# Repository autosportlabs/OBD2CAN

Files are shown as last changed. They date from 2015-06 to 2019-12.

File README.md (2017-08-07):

OBD2CAN
=======

OBD2CAN allows cars with pre-CAN OBDII enabled ECUs (1996-2007) to emulate a CAN-OBDII interface.

Target
======

OBD2CAN was originally designed as an enhancement to the RaceCapture and RaceCapture/Pro line of hardware, but could theoretically be used with any device that can only communicate with CAN-OBDII enabled ECUs.

Principal of Operation
======================

The operation of OBD2CAN is straightforward:

CAN-OBDII requests are received by OBD2CAN and are forwarded on to the legacy-OBDII interface, using
a STN1110 processor and interface circuitry. 

Legacy-OBDII PID responses are received from the STN1110, and transformed back into the equivalent CAN-OBDII response.

Firmware
========
The firmware is targeted for the STM32F072, and uses ChibiOS as a RTOS. 

Compiling
=========
Compiling requires arm-none-eabi gcc version 4.7.4 20130913

From the firmware directory issue:

> make clean

> make

Flashing
========
* ST bootloader

The firmware image can be flashed using the ST bootloader using the USART1 header after activating BOOT mode. On the OBD2CAN hardware the BOOT jumper pads is adjacent to the USART1 header. The USART header can be connected to a common FTDI 3.3v USB-USART cable (TTL-232R-3V3).

* JTAG SWD

An openocd script is provided to flash the STM32 via SWD, using a ST-LINK/V2

Operation
=========

CAN PID requests are received per OBDII SAE specifications and are translated 1:1 to STN1110 PID requests for the target ECU. 
* 500KBPS
* 11 bit

Protocol is set for automatic detection. 

Diagnostic and command/control CAN messages
===========================================

Control Message
===============
The control message allows some control over the OBD2CAN module's settings

CAN ID: 62344

* Byte 0: Sub command.
 * always 0x01

* Byte 1: Debug level on UART header
 * 0: no logging
 * 1: info level logging
 * 2: trace level logging

* Byte 2: Reset STN1110
 * 0: do not reset
 * 1: perform a hard reset

* Byte 3: Set OBDII protocol
Affects AT SP command, see ELM327 manual. If different than the current setting, triggers a reset of the STN1110
 * 0: auto detect (power up default)
 * 1: J1850 PWM
 * 2: J1850 VPW
 * 3: ISO 9141-2
 * 4: ISO 14230-4

Diagnostic
==========
The OBD2CAN will broadcast a diagnostic message at 1Hz with the following information:

CAN ID: 62345

* Byte 0: Detected protocol
 * 0: auto detect (still detecting)
 * 1: J1850 PWM
 * 2: J1850 VPW
 * 3: ISO 9141-2
 * 4: ISO 14230-4

* Byte 1: Last error code
 * 0: STN1110_ERROR_NONE,
 * 1: STN1110_ERROR_STOPPED,
 * 2: STN1110_ERROR_NO_DATA,
 * 3: STN1110_ERROR_BUS_INIT

* Byte 2-3: STN1110 request/reply latency, in ms. 
 * Little Endian

* Byte 4: reserved

* Byte 5: firmware major version

* Byte 6: firmware minor version

* Byte 7: firmware patch version

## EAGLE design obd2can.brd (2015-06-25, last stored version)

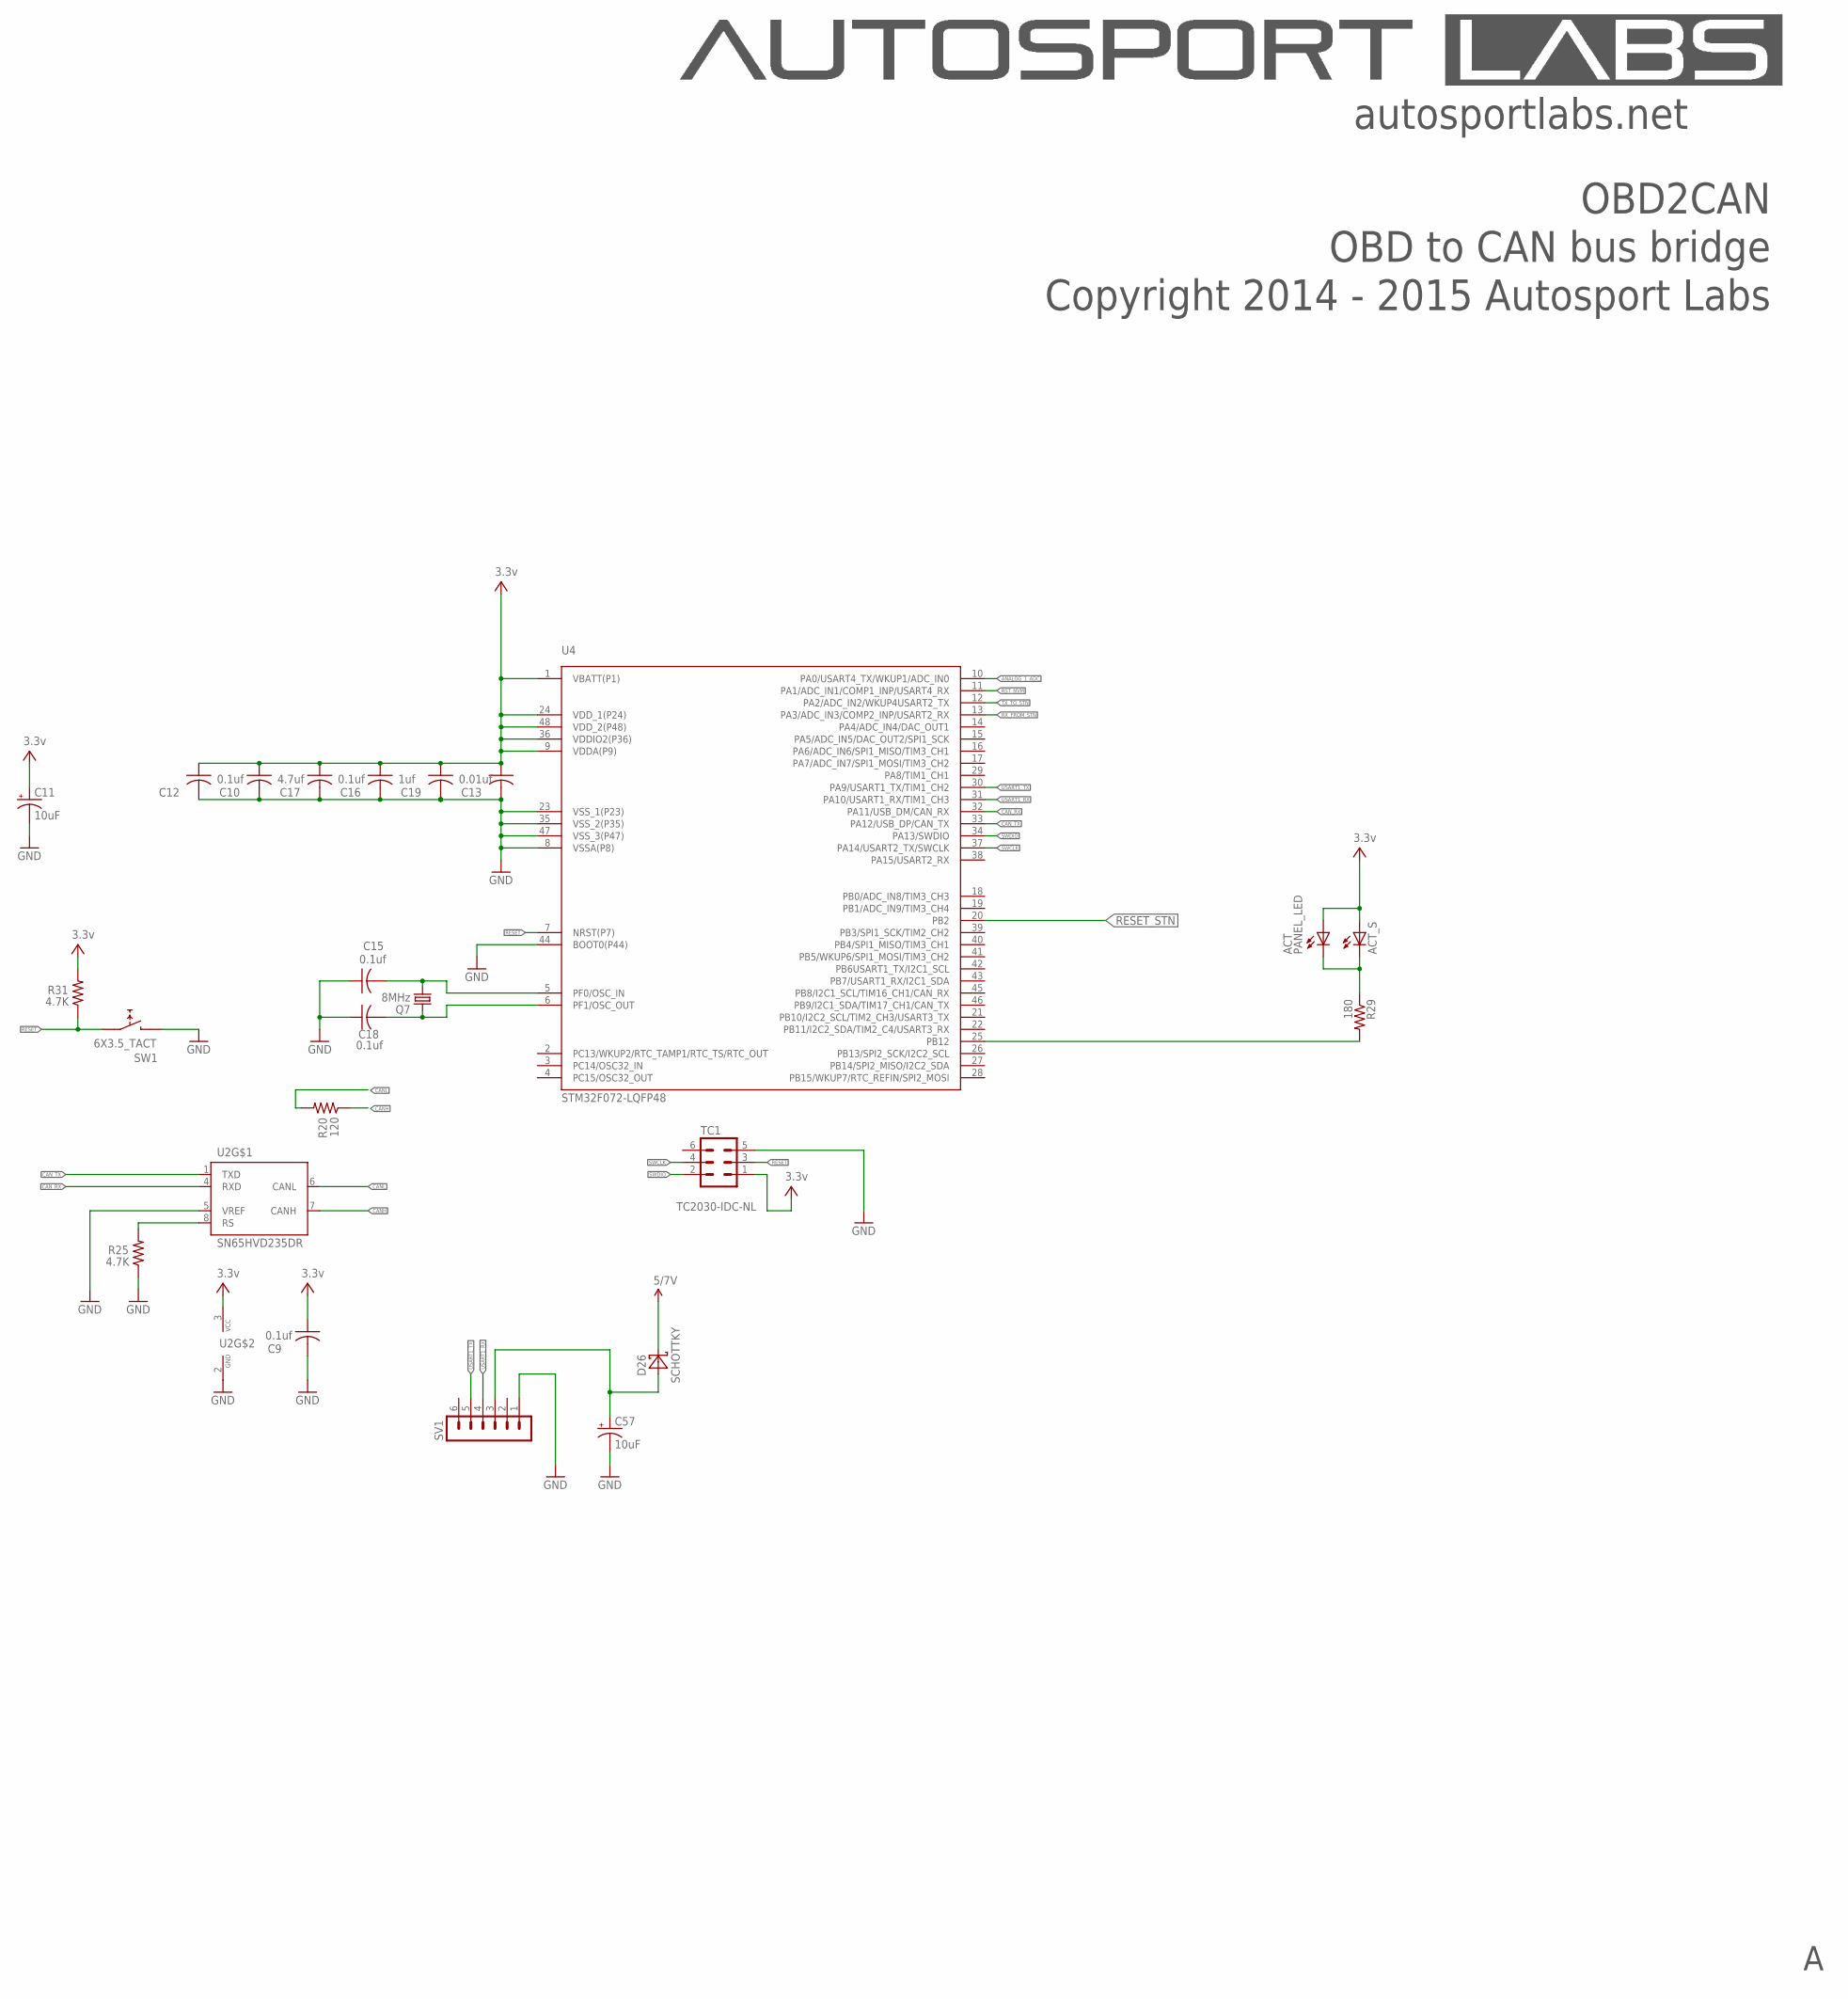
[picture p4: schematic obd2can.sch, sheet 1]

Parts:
ACT: PANEL_LED; RIGHTANGLE_CML_5323F5
ACT_S: LEDCHIPLED_0603; CHIPLED_0603
C9, C10, C15, C16, C18: 0.1uf; C0603K
C11, C57: 10uF; SMC_A
C12, C17: 4.7uf; C0603K
C13: 0.01uf; C0603K
C19: 1uf; C0603K
D26: SCHOTTKY; SMA
Q7: 8MHz; CRYSTAL-SMD-5X3
R20: 120; R0603
R25, R31: 4.7K; R0603
R29: 180; 0402-RES
SV1: MA06-1
SW1: 6X3.5_TACT; TACT_6X3.5
TC1: TC2030-IDC-NL
U2: SN65HVD235DR; SO08
U4: STM32F072-LQFP48; LQFP48

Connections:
ANALOG_1_ADC: U4.10 (PA0/USART4_TX/WKUP1/ADC_IN0)
CANH: R20.1, U2.7 (CANH); also elsewhere on the board
CANL: R20.2, U2.6 (CANL); also elsewhere on the board
CAN_RX: U2.4 (RXD), U4.32 (PA11/USB_DM/CAN_RX)
CAN_TX: U2.1 (TXD), U4.33 (PA12/USB_DP/CAN_TX)
GND: C9.2, C10.2, C11.-, C12.2, C13.2, C15.1, C16.2, C17.2, C18.1, C19.2, C57.-, R25.1, SV1.1, SW1.P$2 (2), TC1.5, U2.2 (GND), U2.5 (VREF), U4.8 (VSSA(P8)), U4.23 (VSS_1(P23)), U4.35 (VSS_2(P35)), U4.44 (BOOT0(P44)), U4.47 (VSS_3(P47)); also elsewhere on the board
GND1: ACT.C, ACT_S.C, R29.1
unnamed: R29.2, U4.25 (PB12)
unnamed: R25.2, U2.8 (RS)
unnamed: C18.2, Q7.3 (2), U4.6 (PF1/OSC_OUT)
unnamed: C15.2, Q7.1, U4.5 (PF0/OSC_IN)
RESET: R31.1, SW1.P$1 (1), TC1.3, U4.7 (NRST(P7))
RESET_STN: U4.20 (PB2); also elsewhere on the board
RST_NVM: U4.11 (PA1/ADC_IN1/COMP1_INP/USART4_RX); also elsewhere on the board
RX_FROM_STN: U4.13 (PA3/ADC_IN3/COMP2_INP/USART2_RX); also elsewhere on the board
SWCLK: TC1.4, U4.37 (PA14/USART2_TX/SWCLK)
SWDIO: TC1.2, U4.34 (PA13/SWDIO)
TX_TO_STN: U4.12 (PA2/ADC_IN2/WKUP4USART2_TX); also elsewhere on the board
USART1_RX: SV1.4, U4.31 (PA10/USART1_RX/TIM1_CH3)
USART1_TX: SV1.5, U4.30 (PA9/USART1_TX/TIM1_CH2)
V+: ACT.A, ACT_S.A, C9.1, C10.1, C11.+, C12.1, C13.1, C16.1, C17.1, C19.1, R31.2, TC1.1, U2.3 (VCC), U4.1 (VBATT(P1)), U4.9 (VDDA(P9)), U4.24 (VDD_1(P24)), U4.36 (VDDIO2(P36)), U4.48 (VDD_2(P48)); also elsewhere on the board
VBUS: C57.+, D26.A, SV1.3
VCC: D26.C; also elsewhere on the board

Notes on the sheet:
Copyright 2014 - 2015 Autosport Labs
OBD2CAN
autosportlabs.net
OBD to CAN bus bridge

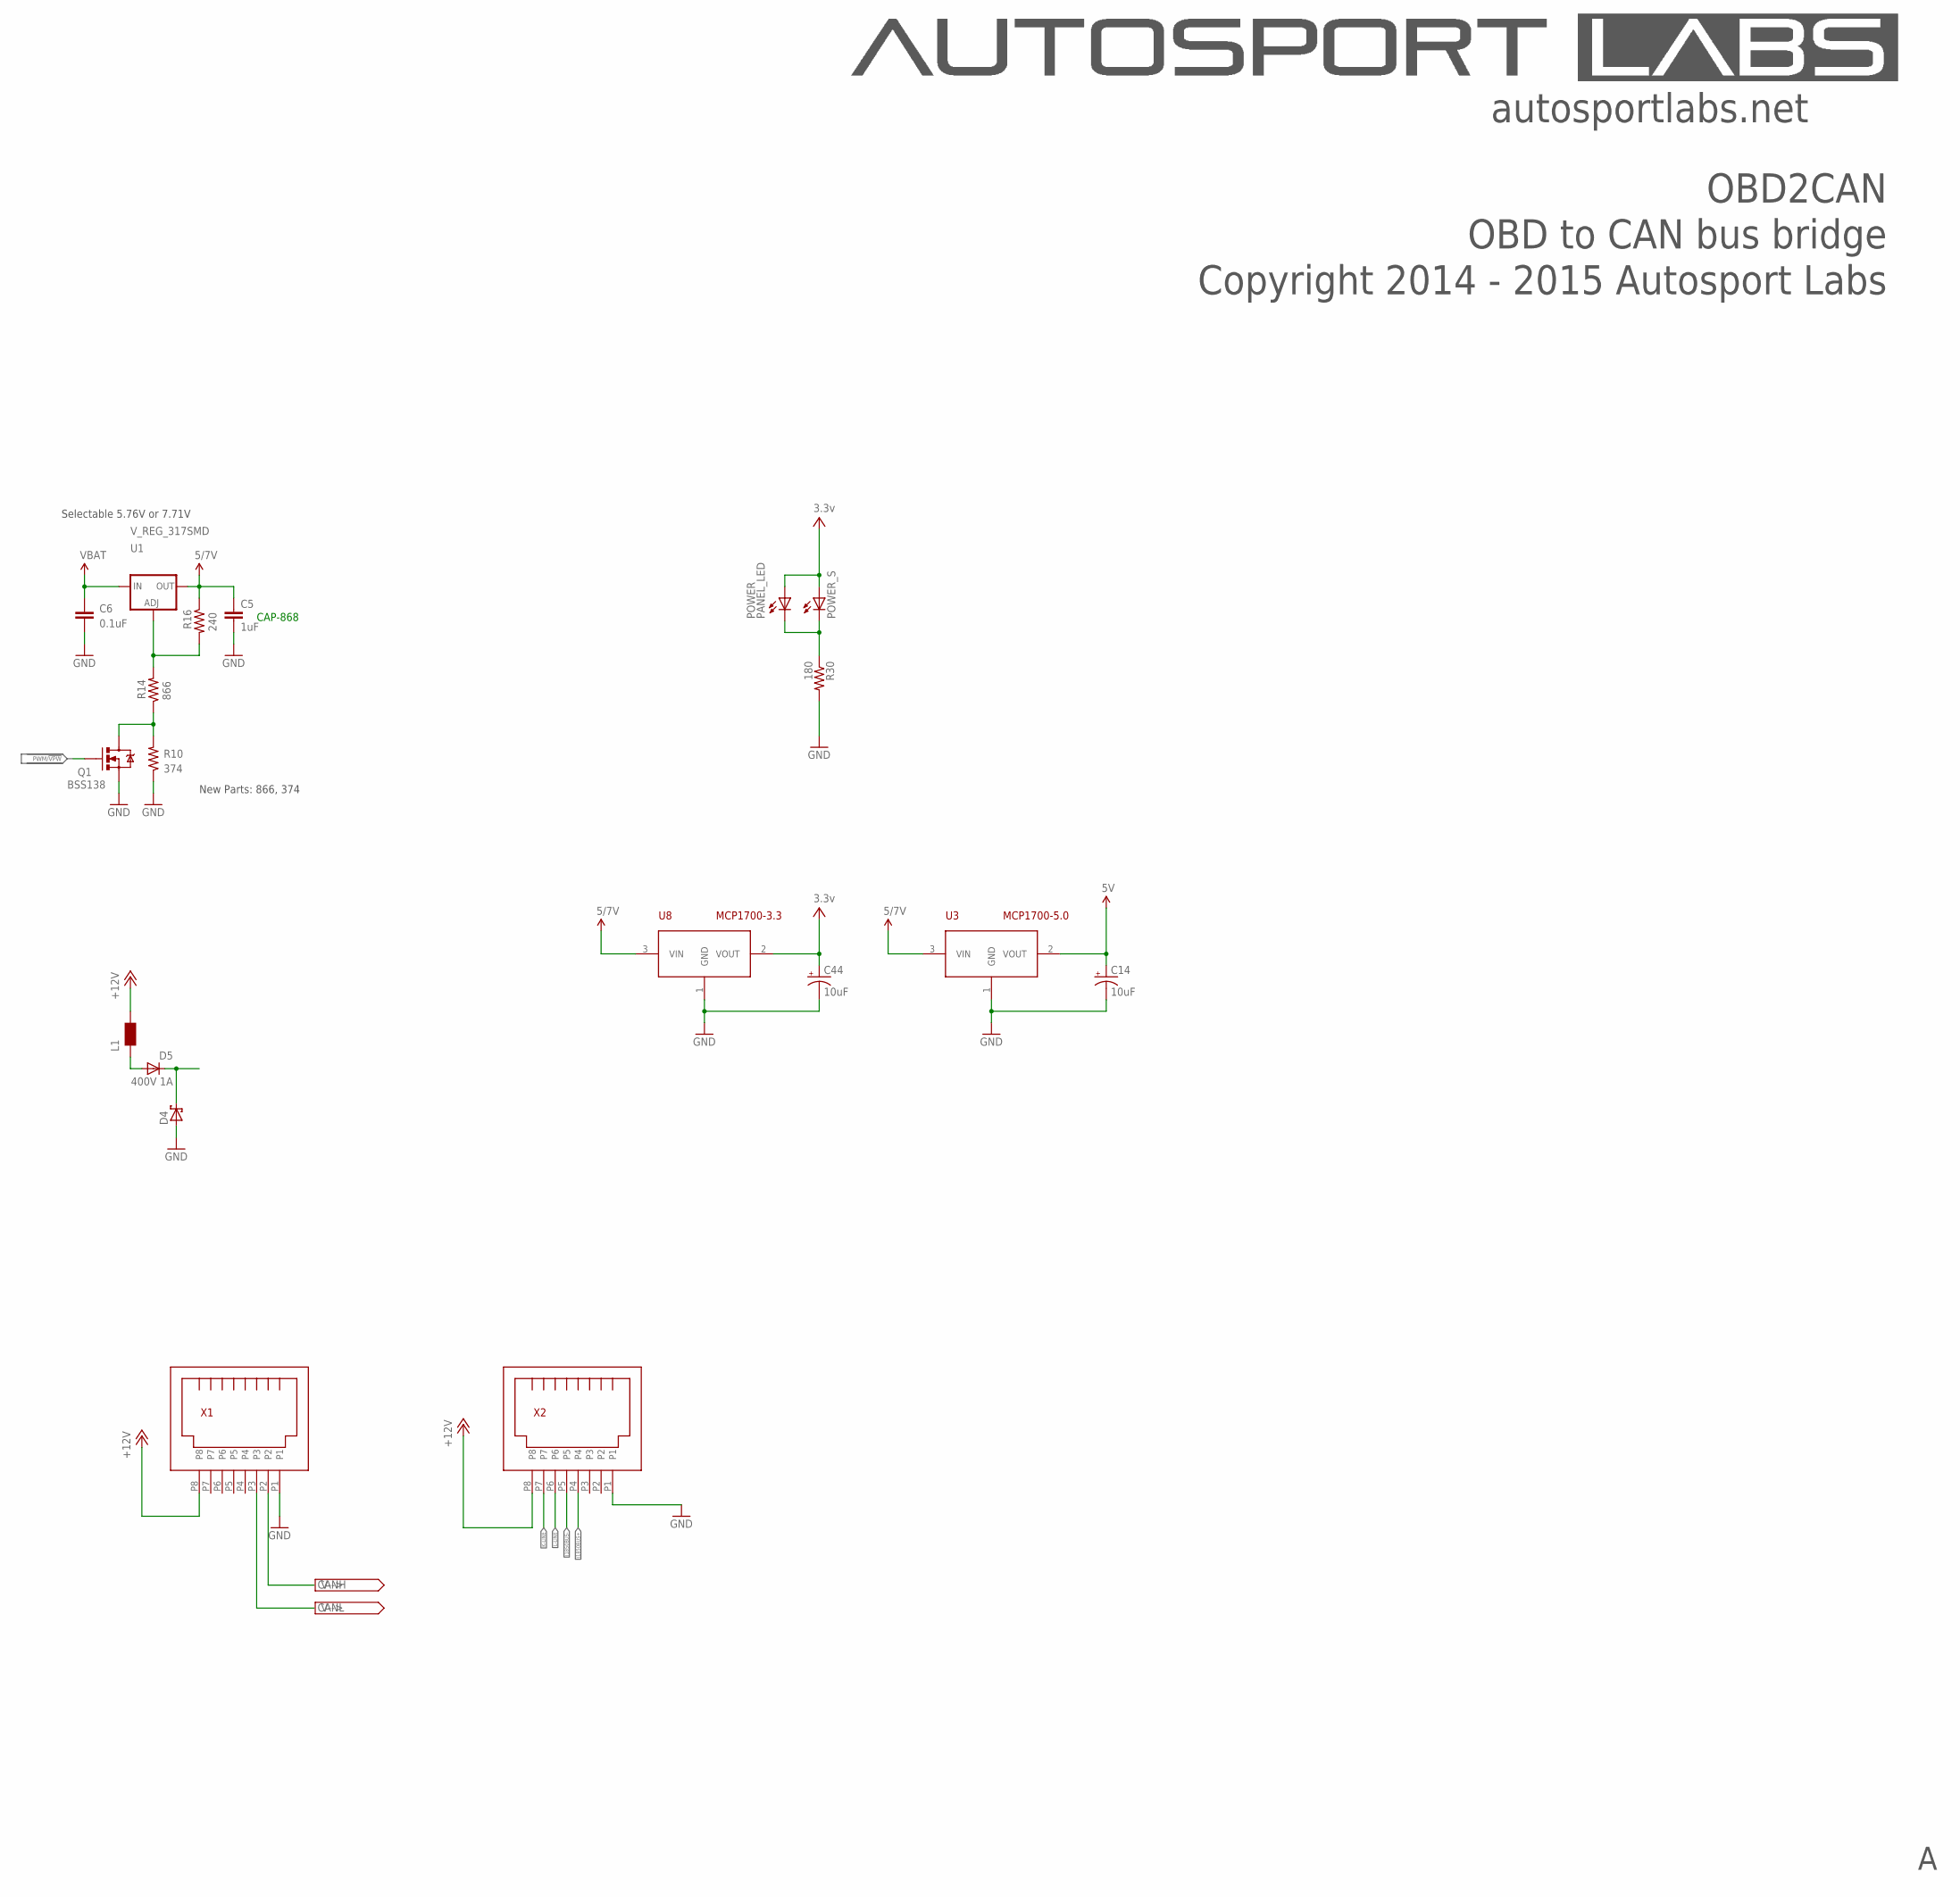
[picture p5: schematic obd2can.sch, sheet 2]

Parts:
C5: 1uF; 0402-CAP
C6: 0.1uF; 0402-CAP
C14, C44: 10uF; SMC_A
D4: SCHOTTKY-DIODESMC; SMC
D5: 400V 1A; SMA
L1: WE-CBF_1812; 1812
POWER: PANEL_LED; RIGHTANGLE_CML_5323F5
POWER_S: LEDCHIPLED_0603; CHIPLED_0603
Q1: BSS138; SOT23-3
R10: 374; 0402-RES
R14: 866; 0402-RES
R16: 240; 0402-RES
R30: 180; 0402-RES
U1: V_REG_317SMD; SOT223
U3: MCP1700-5.0; SOT-23
U8: MCP1700-3.3; SOT-23
X1, X2: RJ45_RIGHT_ANGLEMOLEX_95001-2881; RJ45_RIGHT_ANGLE_MOLEX_95001-2881

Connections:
5V: C14.+, U3.2 (VOUT); also elsewhere on the board
+12V: L1.2, X1.P8, X2.P8; also elsewhere on the board
CANH: X1.P2; also elsewhere on the board
CANL: X1.P3; also elsewhere on the board
GND: C5.2, C6.2, C14.-, C44.-, D4.A, Q1.2 (S), R10.1, R30.2, U3.1 (GND), U8.1 (GND), X1.P1, X2.P1; also elsewhere on the board
GND2: POWER.C, POWER_S.C, R30.1
J1850BUS+: X2.P4; also elsewhere on the board
J1850BUS-: X2.P5; also elsewhere on the board
K-LINE: X2.P7; also elsewhere on the board
L-LINE: X2.P6; also elsewhere on the board
unnamed: R14.2, R16.2, U1.1 (ADJ)
unnamed: Q1.3 (D), R10.2, R14.1
unnamed: D5.A, L1.1
PWM/!VPW: Q1.1 (G); also elsewhere on the board
SAFE12V: C6.1, D4.C, D5.C, U1.3 (IN); also elsewhere on the board
V+: C44.+, POWER.A, POWER_S.A, U8.2 (VOUT); also elsewhere on the board
VCC: C5.1, R16.1, U1.2 (OUT), U3.3 (VIN), U8.3 (VIN); also elsewhere on the board

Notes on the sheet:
Copyright 2014 - 2015 Autosport Labs
OBD2CAN
autosportlabs.net
OBD to CAN bus bridge
Selectable 5.76V or 7.71V
New Parts: 866, 374
CAP-868

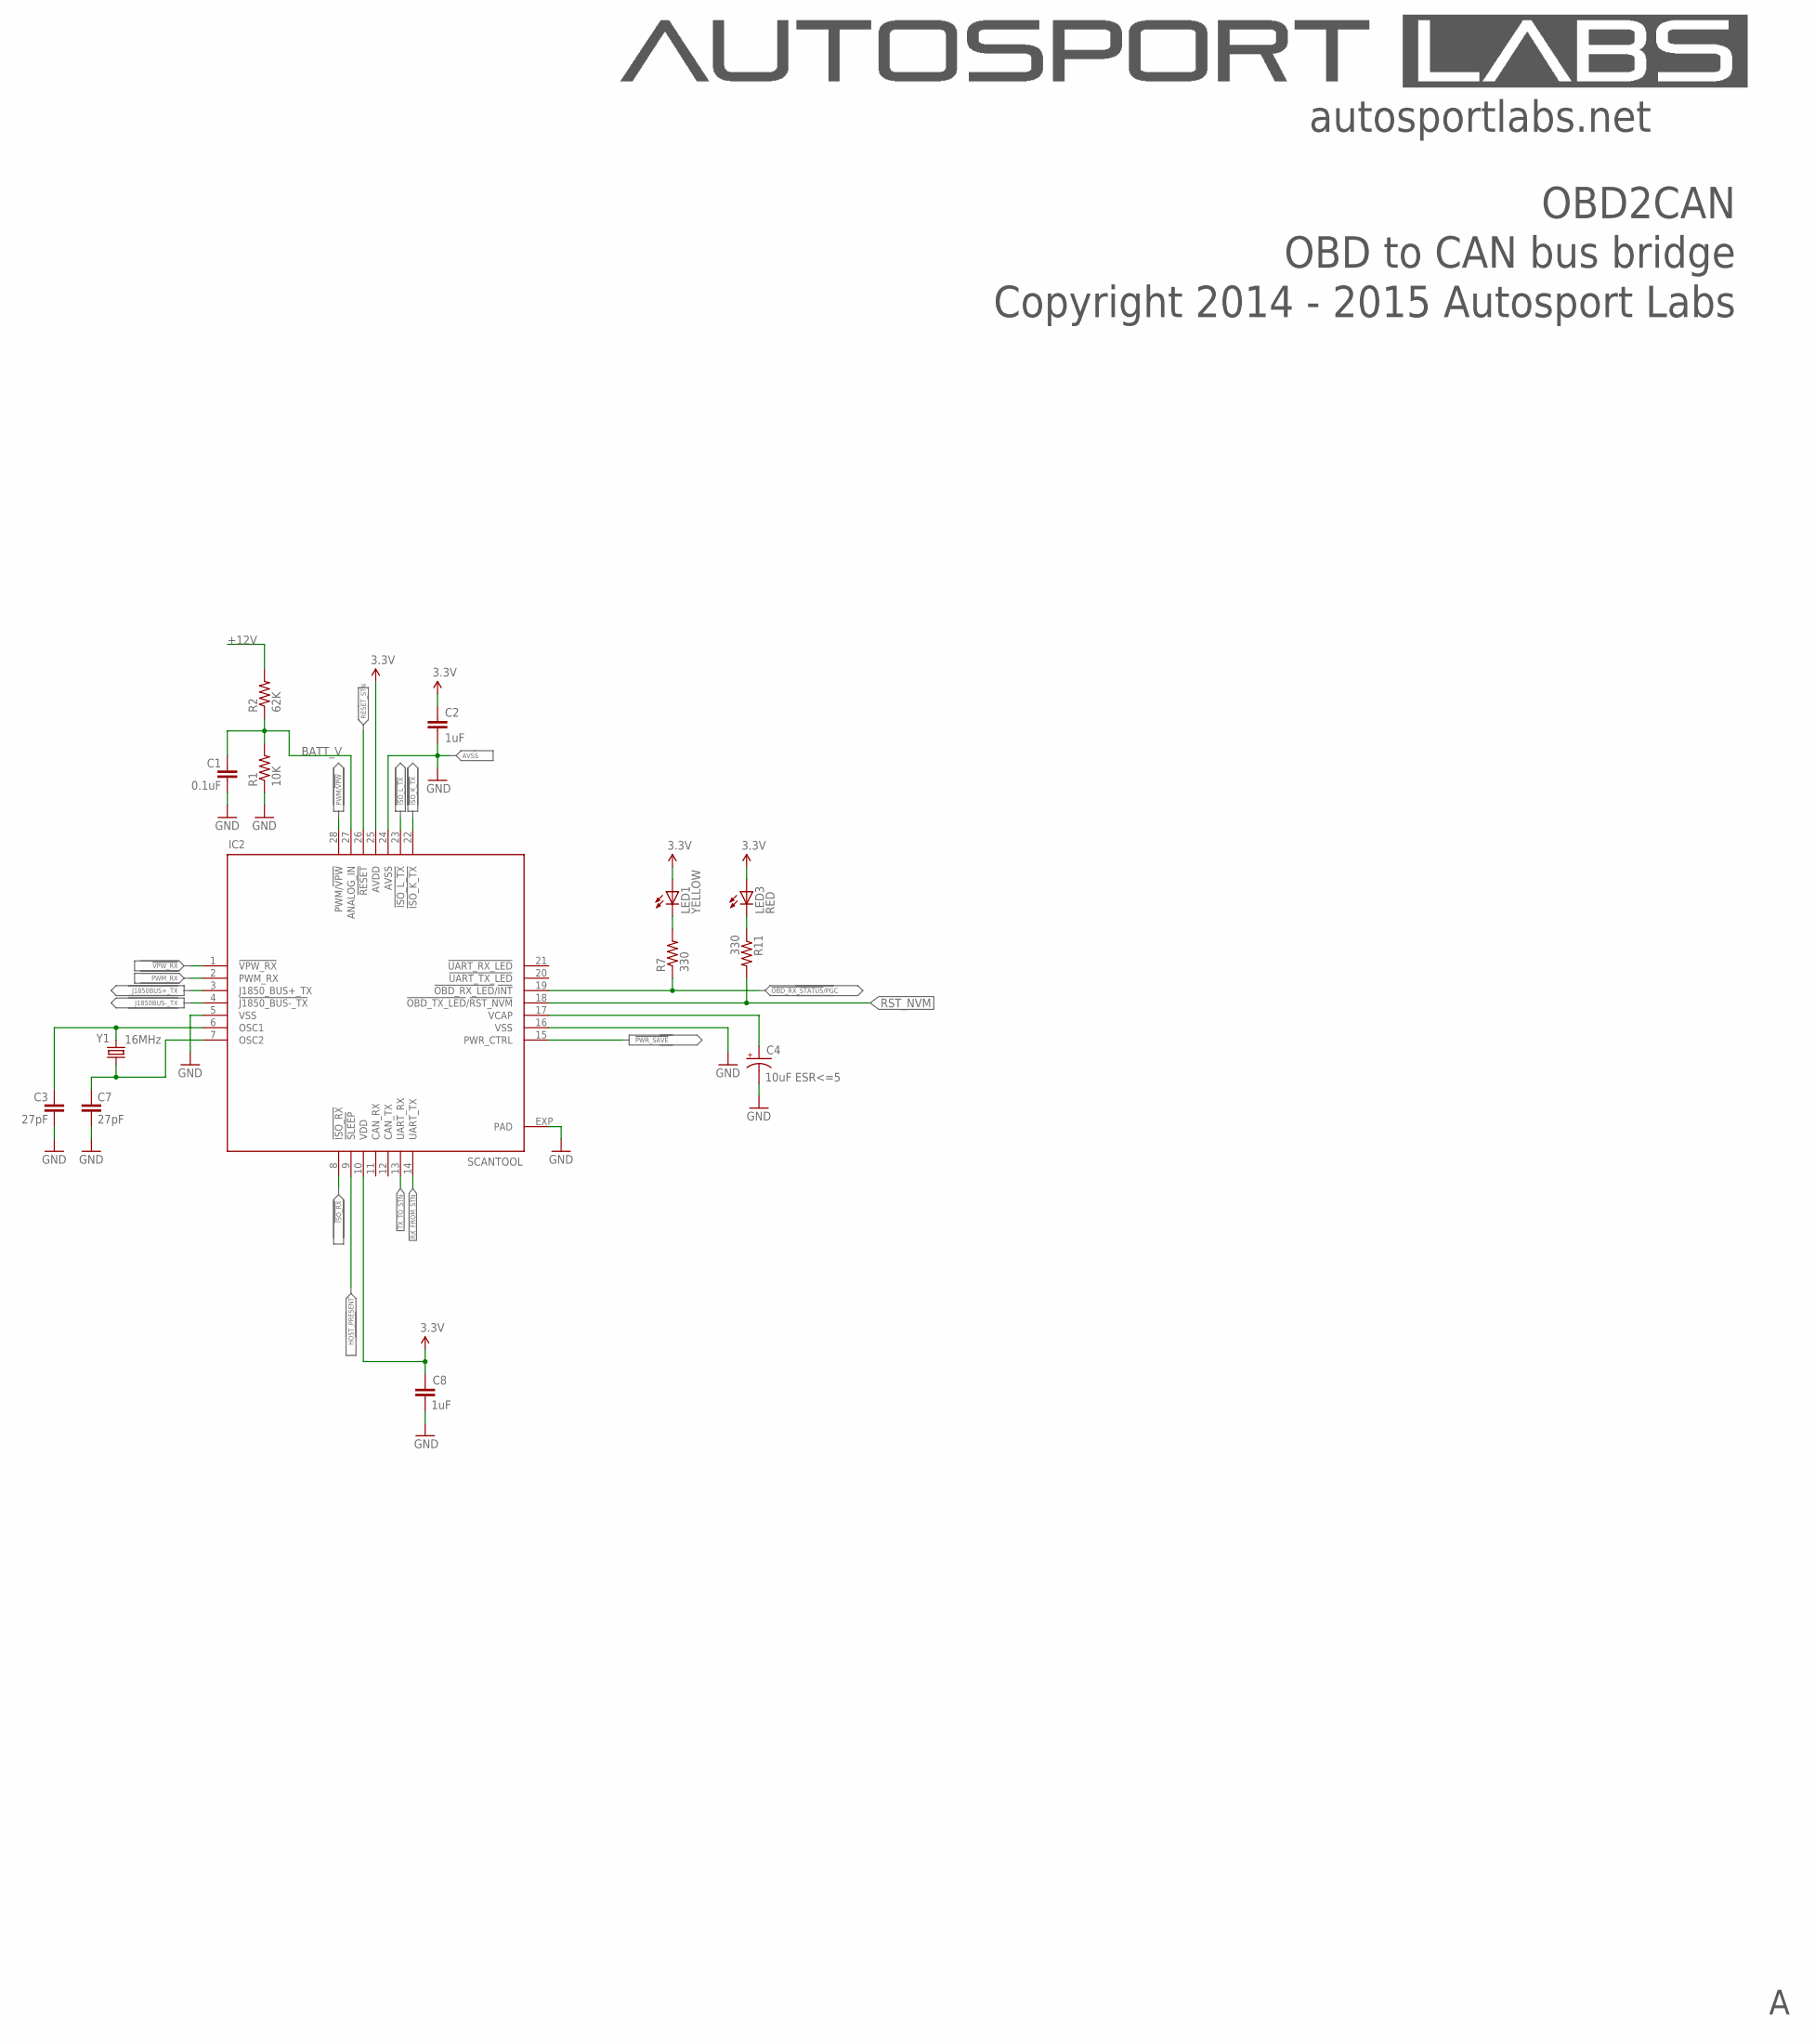
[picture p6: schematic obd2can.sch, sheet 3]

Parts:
C1: 0.1uF; 0402-CAP
C2, C8: 1uF; 0402-CAP
C3, C7: 27pF; 0402-CAP
C4: 10uF ESR<=5; EIA3216
IC2: SCANTOOL; _STN_SCANTOOL_QFN-28-S
LED1: YELLOW; LED-0603
LED3: RED; LED-0603
R1: 10K; 0402-RES
R2: 62K; 0402-RES
R7, R11: 330; 0402-RES
Y1: 16MHz; CRYSTAL-SMD-5X3

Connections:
!ISO_K_TX: IC2.22 (!ISO_K_TX); also elsewhere on the board
!ISO_L_TX: IC2.23 (!ISO_L_TX); also elsewhere on the board
!ISO_RX: IC2.8 (!ISO_RX); also elsewhere on the board
!OBD_RX_STATUS!/PGC: IC2.19 (!OBD_RX_LED!/!INT), R7.1
!PWR_SAVE: IC2.15 (PWR_CTRL)
!VPW_RX: IC2.1 (!VPW_RX); also elsewhere on the board
+12V: R2.2; also elsewhere on the board
BATT_V: C1.1, IC2.27 (ANALOG_IN), R1.2, R2.1
GND: C1.2, C2.2, C3.2, C4.C (-), C7.2, C8.2, IC2.5 (VSS), IC2.16 (VSS), IC2.24 (AVSS), IC2.EXP (PAD), R1.1; also elsewhere on the board
HOST_PRESENT: IC2.9 (!SLEEP)
J1850BUS+_TX: IC2.3 (J1850_BUS+_TX); also elsewhere on the board
J1850BUS-_TX: IC2.4 (!J1850_BUS-_TX); also elsewhere on the board
unnamed: C4.A (+), IC2.17 (VCAP)
unnamed: LED1.C, R7.2
unnamed: LED3.C, R11.1
OSC1: C3.1, IC2.6 (OSC1), Y1.3 (2)
OSC2: C7.1, IC2.7 (OSC2), Y1.1
PWM/!VPW: IC2.28 (PWM/!VPW); also elsewhere on the board
PWM_RX: IC2.2 (PWM_RX); also elsewhere on the board
RESET_STN: IC2.26 (!RESET); also elsewhere on the board
RST_NVM: IC2.18 (!OBD_TX_LED!/!RST_NVM), R11.2; also elsewhere on the board
RX_FROM_STN: IC2.14 (UART_TX); also elsewhere on the board
TX_TO_STN: IC2.13 (UART_RX); also elsewhere on the board
V+: C2.1, C8.1, IC2.10 (VDD), IC2.25 (AVDD), LED1.A, LED3.A; also elsewhere on the board

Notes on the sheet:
AVSS
Copyright 2014 - 2015 Autosport Labs
OBD2CAN
autosportlabs.net
OBD to CAN bus bridge

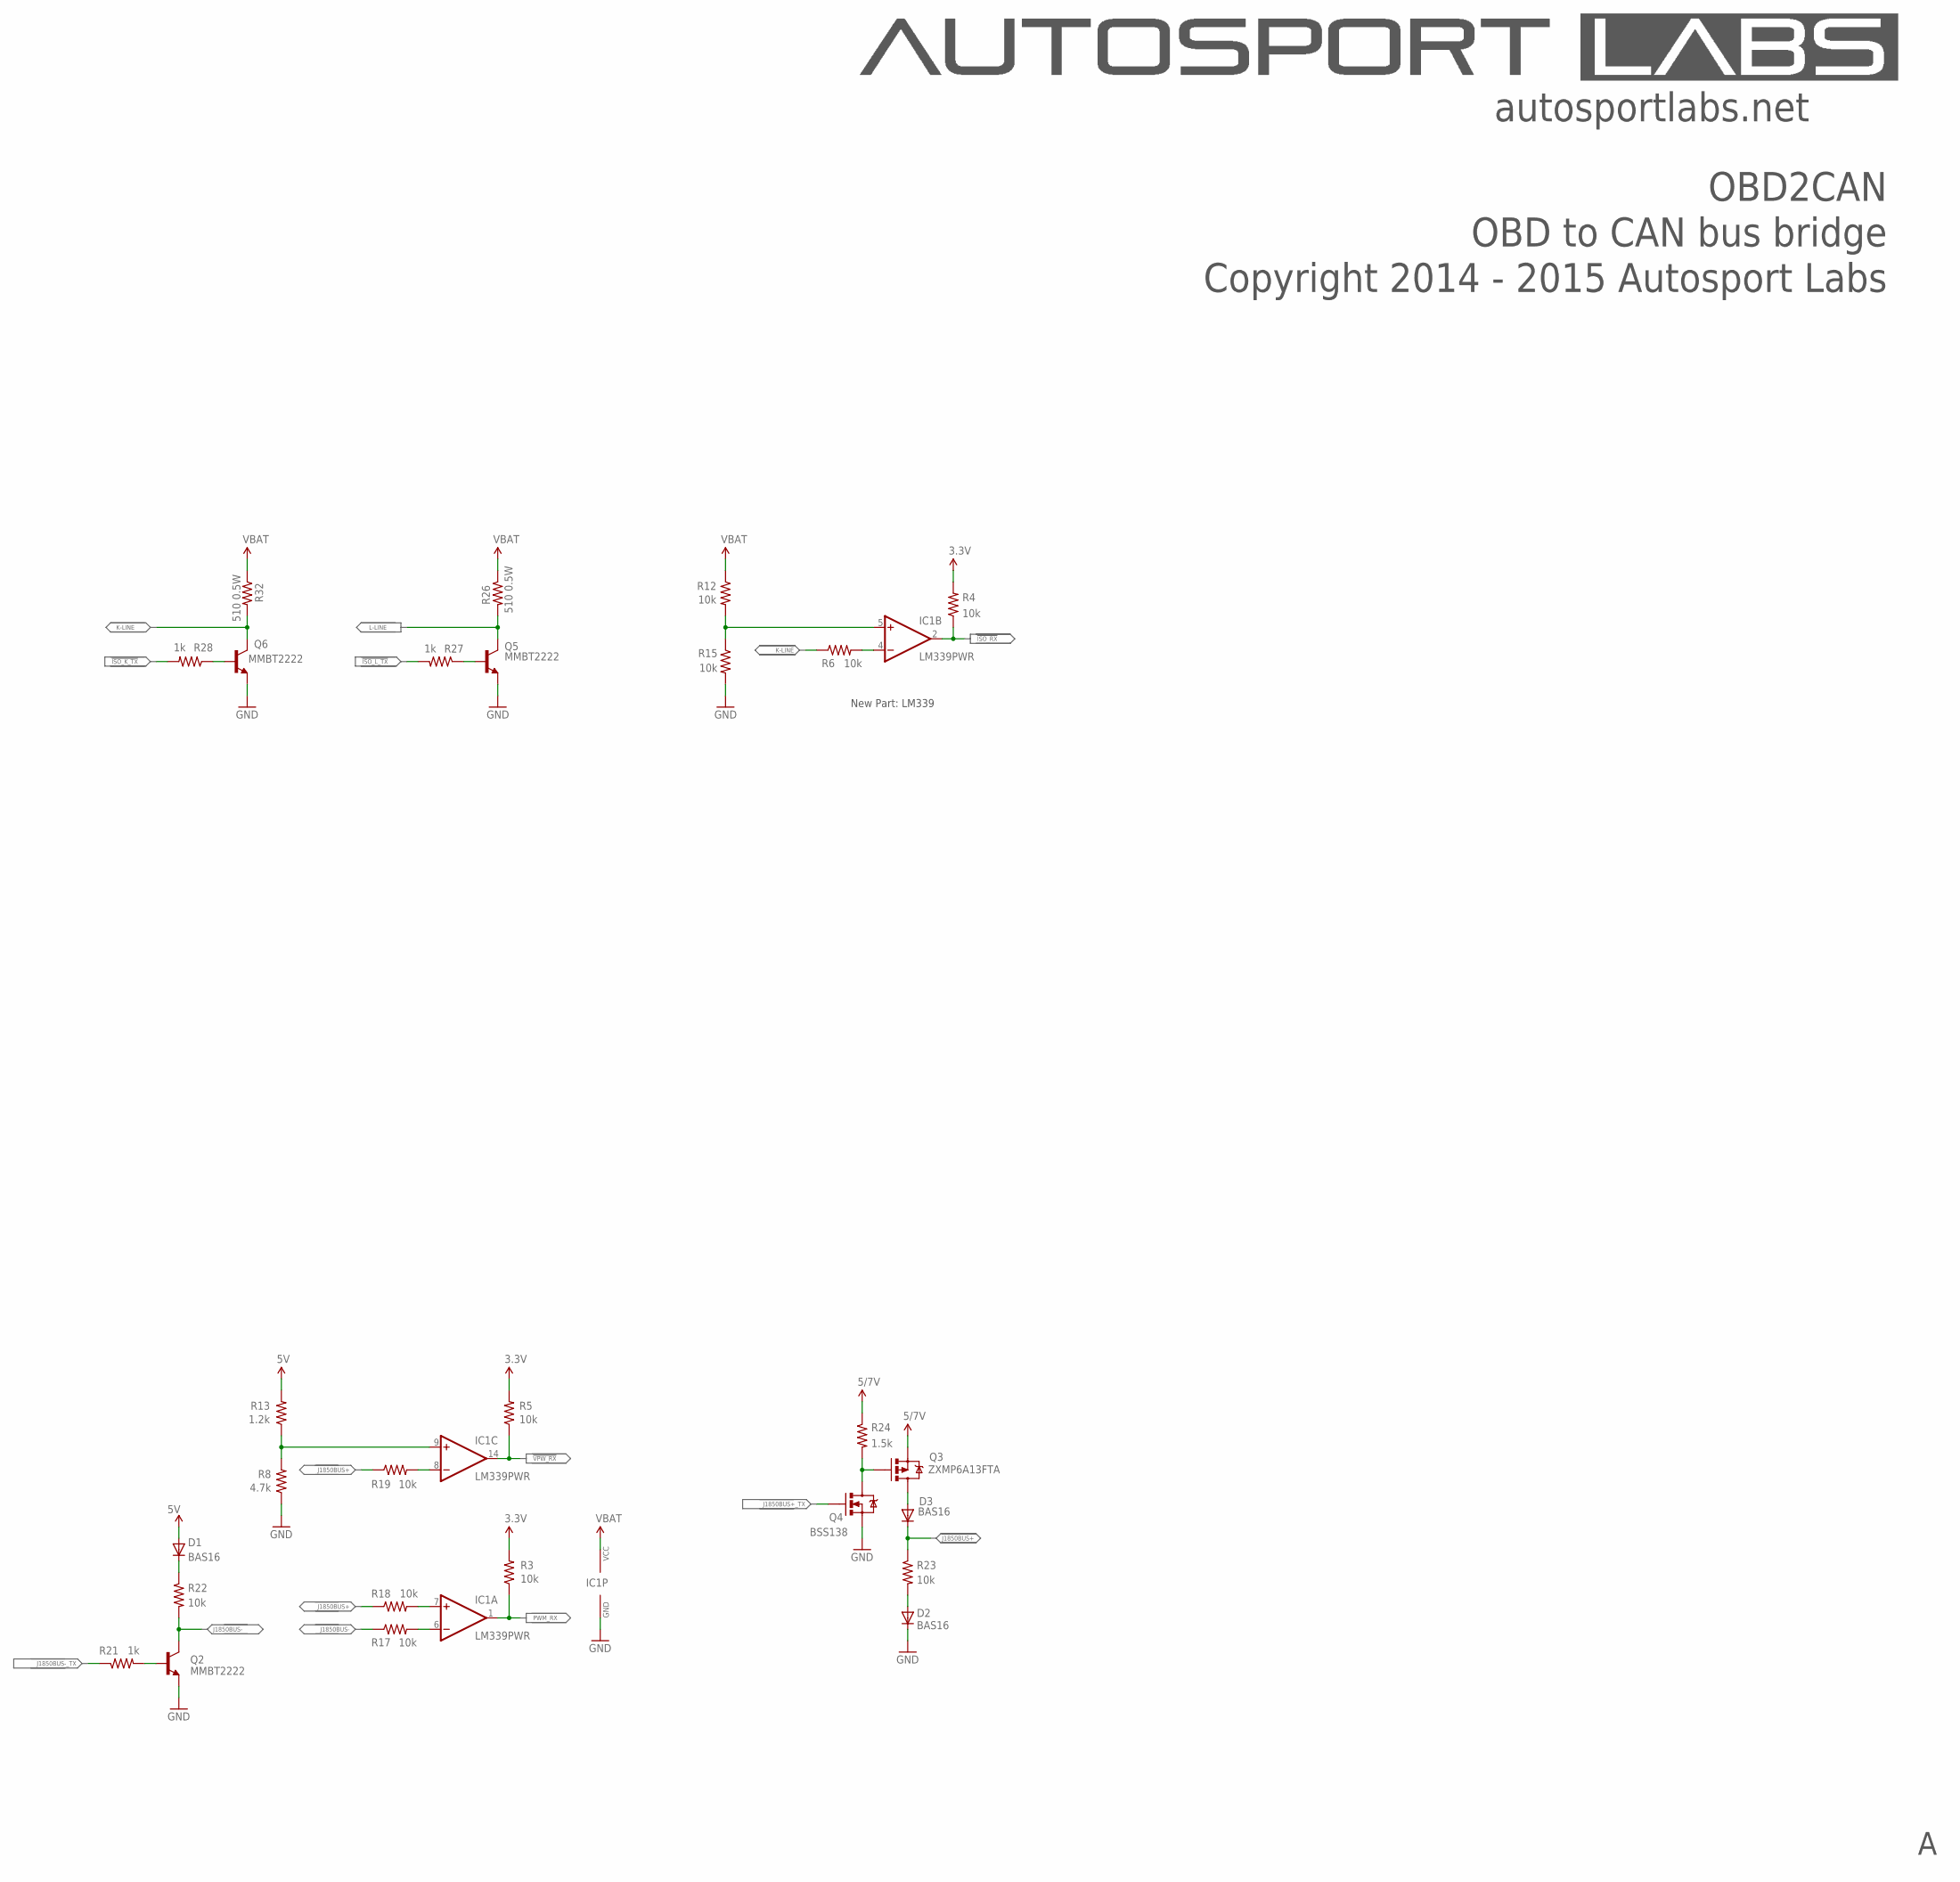
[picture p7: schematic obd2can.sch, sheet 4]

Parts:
D1, D2, D3: BAS16; SOD-323
IC1: LM339PWR; TSSOP-14
Q2, Q5, Q6: MMBT2222; SOT23-3
Q3: ZXMP6A13FTA; SOT23
Q4: BSS138; SOT23-3
R3, R4, R5, R6, R12, R15, R17, R18, R19, R22, R23: 10k; 0402-RES
R8: 4.7k; 0402-RES
R13: 1.2k; 0402-RES
R21, R27, R28: 1k; 0402-RES
R24: 1.5k; 0402-RES
R26, R32: 510 0.5W; 2010

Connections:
5V: D1.2 (A), R13.2; also elsewhere on the board
!ISO_K_TX: R28.2; also elsewhere on the board
!ISO_L_TX: R27.2; also elsewhere on the board
!ISO_RX: IC1.2 (OUT), R4.1; also elsewhere on the board
!VPW_RX: IC1.14 (OUT), R5.1; also elsewhere on the board
GND: D2.1 (C), IC1.12 (GND), Q2.2 (E), Q4.2 (S), Q5.2 (E), Q6.2 (E), R8.1, R15.2; also elsewhere on the board
J1850BUS+: D3.1 (C), R18.1, R19.1, R23.1; also elsewhere on the board
J1850BUS+_TX: Q4.1 (G); also elsewhere on the board
J1850BUS-: Q2.3 (C), R17.1, R22.2; also elsewhere on the board
J1850BUS-_TX: R21.1; also elsewhere on the board
K-LINE: Q6.3 (C), R6.1, R32.2; also elsewhere on the board
L-LINE: Q5.3 (C), R26.2; also elsewhere on the board
unnamed: IC1.7 (+IN), R18.2
unnamed: IC1.6 (-IN), R17.2
unnamed: Q6.1 (B), R28.1
unnamed: Q5.1 (B), R27.1
unnamed: IC1.5 (+IN), R12.2, R15.1
unnamed: IC1.8 (-IN), R19.2
unnamed: D3.2 (A), Q3.3 (D)
unnamed: IC1.9 (+IN), R8.2, R13.1
unnamed: IC1.4 (-IN), R6.2
unnamed: D1.1 (C), R22.1
unnamed: Q3.1 (G), Q4.3 (D), R24.2
unnamed: D2.2 (A), R23.2
unnamed: Q2.1 (B), R21.2
PWM_RX: IC1.1 (OUT), R3.1; also elsewhere on the board
SAFE12V: IC1.3 (VCC), R12.1, R26.1, R32.1; also elsewhere on the board
V+: R3.2, R4.2, R5.2; also elsewhere on the board
VCC: Q3.2 (S), R24.1; also elsewhere on the board

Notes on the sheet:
Copyright 2014 - 2015 Autosport Labs
OBD2CAN
autosportlabs.net
OBD to CAN bus bridge
New Part: LM339

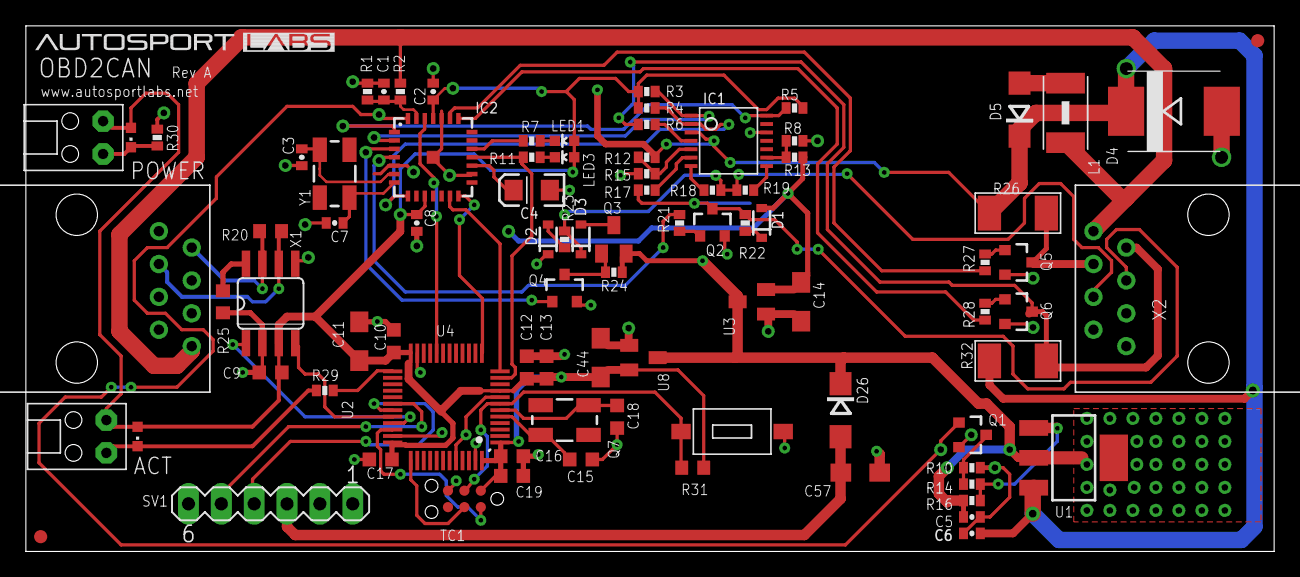
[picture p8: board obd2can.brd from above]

Board: 2 copper layers, 96.5 x 40.6 mm, 85 parts (0 on the bottom side), 61 nets.

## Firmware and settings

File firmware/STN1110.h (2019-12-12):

/*
 * OBD2CAN firmware
 *
 * Copyright (C) 2016 Autosport Labs
 *
 * This file is part of the Race Capture firmware suite
 *
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
 * See the GNU General Public License for more details. You should
 * have received a copy of the GNU General Public License along with
 * this code. If not, see <http://www.gnu.org/licenses/>.
 */

#ifndef STN1110_H_
#define STN1110_H_
#include "ch.h"
#include "hal.h"

enum obdii_adaptive_timing {
    obdii_adaptive_timing_disabled,
    obdii_adaptive_timing_normal,
    obdii_adaptive_timing_aggressive
};

enum obdii_protocol {
    obdii_protocol_auto,
    obdii_protocol_j1850_pwm,
    obdii_protocol_j1850_vpw,
    obdii_protocol_9141_2,
    obdii_protocol_iso14230_4_kwp_5baud,
    obdii_protocol_iso14230_4_fast_init
};

#define ADAPTIVE_TIMING_DISABLED 0
#define DEFAULT_OBDII_PROTOCOL obdii_protocol_auto
#define DEFAULT_OBDII_ADAPTIVE_TIMING obdii_adaptive_timing_normal
#define DEFAULT_OBDII_TIMEOUT ADAPTIVE_TIMING_DISABLED

void stn1110_reset(enum obdii_protocol protocol, enum obdii_adaptive_timing adaptive_timing, uint8_t obdii_timeout);
void send_stn1110_pid_request(uint8_t * data, size_t data_len);
void stn1110_worker(void);

void check_voltage_regulator_control(void);
#endif /* STN1110_H_ */

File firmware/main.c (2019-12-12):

/*
 * OBD2CAN firmware
 *
 * Copyright (C) 2016 Autosport Labs
 *
 * This file is part of the Race Capture firmware suite
 *
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
 * See the GNU General Public License for more details. You should
 * have received a copy of the GNU General Public License along with
 * this code. If not, see <http://www.gnu.org/licenses/>.
 */

#include "ch.h"
#include "hal.h"
#include "settings.h"
#include "logging.h"
#include "STN1110.h"
#include "system.h"
#include "system_serial.h"
#include "system_CAN.h"

#define CAN_THREAD_STACK 256
#define STN1110_THREAD_STACK 256
#define MAIN_THREAD_SLEEP_NORMAL_MS 10000
#define MAIN_THREAD_SLEEP_FINE_MS   1000
#define MAIN_THREAD_CHECK_INTERVAL_MS 100
#define WATCHDOG_TIMEOUT 11000
#define WATCHDOG_ENABLED true

/*
 * CAN receiver thread.
 */
static THD_WORKING_AREA(can_rx_wa, CAN_THREAD_STACK);
static THD_FUNCTION(can_rx, arg)
{
    (void)arg;
    chRegSetThreadName("CAN_worker");
    can_worker();
}

/*
 * STN1110 receiver thread.
 */
static THD_WORKING_AREA(wa_STN1110_rx, STN1110_THREAD_STACK);
static THD_FUNCTION(STN1110_rx, arg)
{
    (void)arg;
    chRegSetThreadName("STN1110_worker");
    stn1110_worker();
}

static const WDGConfig wdgcfg = {
        STM32_IWDG_PR_64,
        STM32_IWDG_RL(1000),
        STM32_IWDG_WIN_DISABLED
};

/* Watchdog configuration and initialization
 */
static void _start_watchdog(void)
{
        if (! WATCHDOG_ENABLED)
                return;

        wdgStart(&WDGD1, &wdgcfg);
}

int main(void)
{
   /*
    * System initializations.
    * - HAL initialization, this also initializes the configured device drivers
    *   and performs the board-specific initializations.
    * - Kernel initialization, the main() function becomes a thread and the
    *   RTOS is active.
    */

    /* ChibiOS initialization */
    halInit();
    chSysInit();
    _start_watchdog();

    /* Application specific initialization */
    system_can_init();
    system_serial_init();

   /*
    * Creates the processing threads.
    */
    chThdCreateStatic(wa_STN1110_rx, sizeof(wa_STN1110_rx), NORMALPRIO, STN1110_rx, NULL);
    chThdCreateStatic(can_rx_wa, sizeof(can_rx_wa), NORMALPRIO, can_rx, NULL);

    uint32_t stats_check = 0;
    while (true) {
        chThdSleepMilliseconds(MAIN_THREAD_CHECK_INTERVAL_MS);
        enum logging_levels level = get_logging_level();
        uint32_t stats_threshold = (level == logging_level_trace ? MAIN_THREAD_SLEEP_FINE_MS : MAIN_THREAD_SLEEP_NORMAL_MS);
        stats_check += MAIN_THREAD_CHECK_INTERVAL_MS;
        if (stats_check > stats_threshold) {
            broadcast_stats();
            stats_check = 0;
        }
        if (WATCHDOG_ENABLED)
            wdgReset(&WDGD1);
        check_system_state();
        check_voltage_regulator_control();
    }
    return 0;
}

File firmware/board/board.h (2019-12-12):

/*
    ChibiOS - Copyright (C) 2006..2016 Giovanni Di Sirio

    Licensed under the Apache License, Version 2.0 (the "License");
    you may not use this file except in compliance with the License.
    You may obtain a copy of the License at

        http://www.apache.org/licenses/LICENSE-2.0

    Unless required by applicable law or agreed to in writing, software
    distributed under the License is distributed on an "AS IS" BASIS,
    WITHOUT WARRANTIES OR CONDITIONS OF ANY KIND, either express or implied.
    See the License for the specific language governing permissions and
    limitations under the License.
*/

/*
 * This file has been automatically generated using ChibiStudio board
 * generator plugin. Do not edit manually.
 */

#ifndef BOARD_H
#define BOARD_H

/*
 * Setup for ST STM32F072B-Discovery board.
 */

/*
 * Board identifier.
 */
#define BOARD_ST_NUCLEO32_F042K6
#define BOARD_NAME                  "STMicroelectronics NUCLEO32-F042K6"

/*
 * Board oscillators-related settings.
 * NOTE: LSE not fitted.
 * NOTE: HSE is fitted.
 */
#if !defined(STM32_LSECLK)
#define STM32_LSECLK                0U
#endif

#define STM32_LSEDRV                (3U << 3U)

//#if !defined(STM32_HSECLK)
#define STM32_HSECLK                8000000U
//#endif

/* #define STM32_HSE_BYPASS */

/*
 * MCU type as defined in the ST header.
 */
#define STM32F042x6

/*
 * IO pins assignments.
 */
#define GPIOA_ARD_A0                0U
#define GPIOA_ARD_A1                1U
#define GPIOA_VCP_TX                2U
#define GPIOA_ARD_A2                3U
#define GPIOA_ARD_A3                4U
#define GPIOA_ARD_A4                5U
#define GPIOA_ARD_A5                6U
#define GPIOA_ARD_A6                7U
#define GPIOA_ARD_D9                8U
#define GPIOA_ARD_D1                9U
#define GPIOA_ARD_D0                10U
#define GPIOA_ARD_D10               11U
#define GPIOA_ARD_D2                12U
#define GPIOA_SWDIO                 13U
#define GPIOA_SWCLK                 14U
#define GPIOA_VCP_RX                15U

#define GPIOB_ARD_D3                0U
#define GPIOB_ARD_D6                1U
#define GPIOB_PIN2                  2U
#define GPIOB_ARD_D13               3U
#define GPIOB_LED_GREEN             3U
#define GPIOB_ARD_D12               4U
#define GPIOB_ARD_D11               5U
#define GPIOB_ARD_D5                6U
#define GPIOB_ARD_A5_ALT            6U
#define GPIOB_ARD_D4                7U
#define GPIOB_ARD_A4_ALT            7U
#define GPIOB_PIN8                  8U
#define GPIOB_PIN9                  9U
#define GPIOB_PIN10                 10U
#define GPIOB_PIN11                 11U
#define GPIOB_PIN12                 12U
#define GPIOB_PIN13                 13U
#define GPIOB_PIN14                 14U
#define GPIOB_PIN15                 15U

#define GPIOC_PIN0                  0U
#define GPIOC_PIN1                  1U
#define GPIOC_PIN2                  2U
#define GPIOC_PIN3                  3U
#define GPIOC_PIN4                  4U
#define GPIOC_PIN5                  5U
#define GPIOC_PIN6                  6U
#define GPIOC_PIN7                  7U
#define GPIOC_PIN8                  8U
#define GPIOC_PIN9                  9U
#define GPIOC_PIN10                 10U
#define GPIOC_PIN11                 11U
#define GPIOC_PIN12                 12U
#define GPIOC_PIN13                 13U
#define GPIOC_PIN14                 14U
#define GPIOC_PIN15                 15U

#define GPIOD_PIN0                  0U
#define GPIOD_PIN1                  1U
#define GPIOD_PIN2                  2U
#define GPIOD_PIN3                  3U
#define GPIOD_PIN4                  4U
#define GPIOD_PIN5                  5U
#define GPIOD_PIN6                  6U
#define GPIOD_PIN7                  7U
#define GPIOD_PIN8                  8U
#define GPIOD_PIN9                  9U
#define GPIOD_PIN10                 10U
#define GPIOD_PIN11                 11U
#define GPIOD_PIN12                 12U
#define GPIOD_PIN13                 13U
#define GPIOD_PIN14                 14U
#define GPIOD_PIN15                 15U

#define GPIOE_PIN0                  0U
#define GPIOE_PIN1                  1U
#define GPIOE_PIN2                  2U
#define GPIOE_PIN3                  3U
#define GPIOE_PIN4                  4U
#define GPIOE_PIN5                  5U
#define GPIOE_PIN6                  6U
#define GPIOE_PIN7                  7U
#define GPIOE_PIN8                  8U
#define GPIOE_PIN9                  9U
#define GPIOE_PIN10                 10U
#define GPIOE_PIN11                 11U
#define GPIOE_PIN12                 12U
#define GPIOE_PIN13                 13U
#define GPIOE_PIN14                 14U
#define GPIOE_PIN15                 15U
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

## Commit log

2014-02-16 added initial files and license
    [obd2can.brd, obd2can.sch]
2014-02-18 added swdebug and boot button
    [obd2can.brd, obd2can.sch]
2014-02-18 minor label updates
    [obd2can.brd, obd2can.sch]
2014-02-19 grounded vref pin on can transceiver
    [obd2can.brd, obd2can.sch]
2014-05-14 updated readme with improved description and board screenshot
2015-06-05 OBD2CAN WIP
    [obd2can.brd, obd2can.sch]
2015-06-06 combined designs together
    [obd2can.brd, obd2can.sch]
2015-06-06 label adjustment, snapshot image
    [obd2can.brd, obd2can.sch]
2015-06-09 OBD2CAN WIP - more air wires routed
    [obd2can.brd, obd2can.sch]
2015-06-09 only 5 more airwires to route...
    [obd2can.brd]
2015-06-09 fully routed; passes DRC and ERC
    [obd2can.brd, obd2can.sch]
2015-06-09 added the ability to supply power via FTDI header
    [obd2can.brd, obd2can.sch]
2015-06-25 add NVM_RST line between STM32 and STN chips
    [obd2can.brd, obd2can.sch]
2015-06-25 updated board image
2015-06-26 Add script to render PNGs of schematics, boards, and part list
2015-06-26 fix palette in rendered images, link to correct board image in readme
2016-02-01 cleaned up old files
    [obd2can.brd, obd2can.sch]
2016-07-12 removed obsolete CAD files
    [obd2can.brd, obd2can.sch]
2016-07-15 WIP, update ChibiOS, update STN1110 reset
    [board.h, halconf.h, main.c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]
2016-07-15 update new ChibiOS
    [stm_spc56ec74a256s_spc56ec74_minimodule_debug_jtag.cfg, stm_xpc560b64_minimodule_debug_jtag.cfg, stm_xpc560b_spc560d40_minimodule_debug_jtag.cfg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]
2016-08-31 tweak baud rate for 500K. may not be accurate b/c internal oscillator
    [main.c]
2016-08-31 WIP receiving PID requests
2016-09-01 correct PID translation into CAN
    [main.c]
2016-09-01 pass through OBDII request transparently, allowing any PID or mode
2016-09-02 removed unused files
    [stm_spc56ec74a256s_spc56ec74_minimodule_debug_jtag.cfg, stm_xpc560b64_minimodule_debug_jtag.cfg, stm_xpc560b_spc560d40_minimodule_debug_jtag.cfg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]
2016-09-02 refactored thread creation
2016-09-02 added more error handling and tracking
    [STN1110.c, settings.h]
2016-09-02 controllable reset and protocol via can message
    [STN1110.c, settings.h]
2016-09-06 better detect BUS ??? ERROR messages
    [STN1110.c]
2016-09-18 switch to 250K baud for CAN
2016-09-18 refactored to have STN1110 pid request in STN1110.c
2016-09-18 detect protocol after first successful PID response; various other refactorings
2016-09-19 simplify error handling; reset system if there are excessive errors
    [STN1110.c, settings.h]
2016-11-18 request PID from only one ECU, to prevent multiple responses
    [STN1110.c]
2016-11-20 base diagnostic messages on logging level. trace = 1Hz; no logging = 0.1Hz
2016-11-20 switch to 500K clock
2016-11-27 only send diag messages frequently if in trace mode
2017-10-02 WIP migrating to STM32f042
2017-10-02 add invert logic for STN1110 voltage regulator
    [STN1110.c, STN1110.h, main.c]
2019-12-11 STM32F042 WIP
2019-12-11 add new ChibiOS
    [STM32L4+.ods, stm_spc56ec74a256s_spc56ec74_minimodule_debug_jtag.cfg, stm_xpc560b64_minimodule_debug_jtag.cfg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]

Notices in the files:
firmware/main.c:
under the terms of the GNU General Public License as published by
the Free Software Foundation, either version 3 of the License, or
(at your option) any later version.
